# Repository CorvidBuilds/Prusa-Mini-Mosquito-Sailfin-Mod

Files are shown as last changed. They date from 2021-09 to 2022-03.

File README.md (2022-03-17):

# Prusa Mini Mosquito Sailfin Mod
Direct Drive Extruder Mounting Option for Prusa Mini
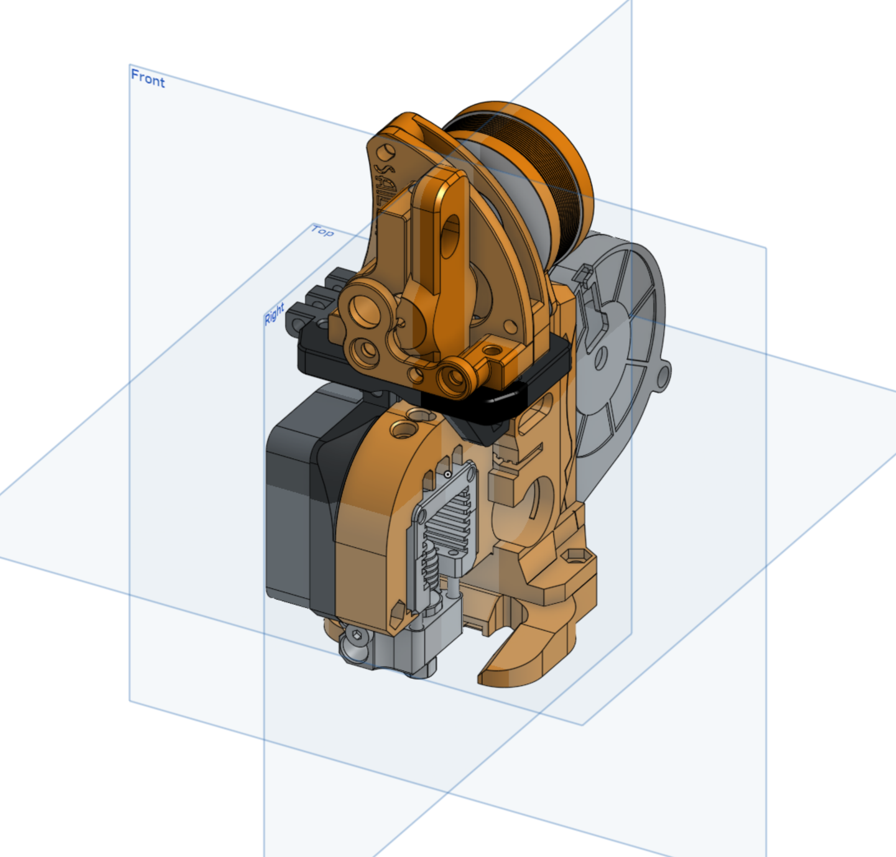
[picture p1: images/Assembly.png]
Assembly

I've been using 4nthonylin's [Mosquito Mount](https://www.prusaprinters.org/prints/36643-prusa-mini-mosquito-mount) and [Fan Shroud](https://www.prusaprinters.org/prints/37368-prusa-mini-mosquito-fan-shroud) mods for a long time and I've wanted to experiment with direct drive extruders for almost as long. I considered putting [Annex Engineering's Sherpa Mini](https://www.prusaprinters.org/prints/32331-prusa-mini-z-axis-bottom-redesign) using [athlon789789's mount](https://www.prusaprinters.org/prints/66519-prusa-mini-sherpa-extruder-direct-drive-conversion) but [CroXY's Sailfin](https://github.com/CroXY3D/Sailfin-Extruder) looked funnier. After some tinkering, I have created these two mounts.

I've been using this without issue since January 2022.

# List of modifications
The Mosquito mount was modified by:

- Removing two nut retainers.
- Removed M6 threading.
- Moved relief to the other side of the feeder hole.

The Sherpa Mini mount was modified by

- Aligning output of extruder with hot end.
- Widening the top plate for said alignment.
- Shortening the overall height by ~3mm.
- Adding a cutout to clear the Z Carriage.

This mount should fit both the Sherpa Mini and the Sailfin (using the Mid_Sherpa_Mount.stl).

# Instructions
- PTFE Length: 40.5mm 
# Klipper Config
Always confirm configurations will work for your system. The below is an example from what works on my Prusa Mini with the Buddy controller board and an LDO 36STH20-1004AHG.
```
#### Sailfin
[extruder]
step_pin: PD9
dir_pin: !PD8
enable_pin: !PD10
microsteps: 32
rotation_distance: 23.5976 
gear_ratio: 50:10
full_steps_per_rotation: 200	#200 for 1.8 degree, 400 for 0.9 degree
nozzle_diameter: 0.400
filament_diameter: 1.750
## Confirm your own thermistor config
# heater_pin: PB1
# sensor_type: ATC Semitec 104GT-2
# sensor_pin: PC0
max_extrude_only_velocity: 70
max_extrude_only_accel: 1500
min_temp: 10
max_temp: 305
## Confirm your own PA values
# pressure_advance = 0.028
# pressure_advance_smooth_time: 0.030
```

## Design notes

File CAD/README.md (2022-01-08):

# CAD Files
Found here: [OnShape](https://cad.onshape.com/documents/62063f3fcb23067bcaa5ab9b/w/d0a171f69a9cdb48ab1417f7/e/0df8f7e7769d611c5ae77dc3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)
Note: Ignore the mounting holes. Sailfin only provides the proprietary mounting holes in CAD instead of the ones that fit Sherpa *and* Sailfin.

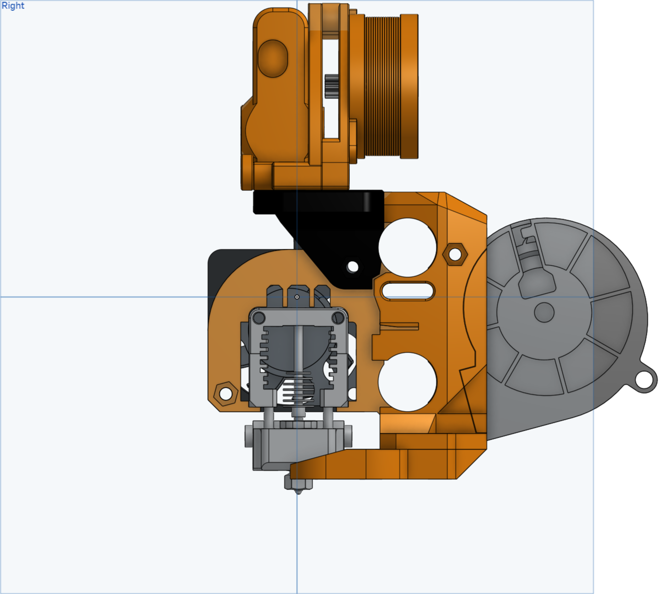
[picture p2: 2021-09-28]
images/Right.png

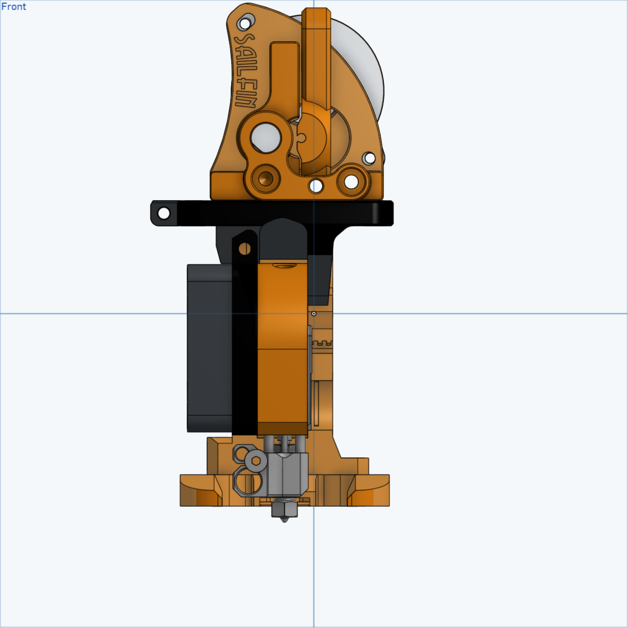
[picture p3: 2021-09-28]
images/Front.png

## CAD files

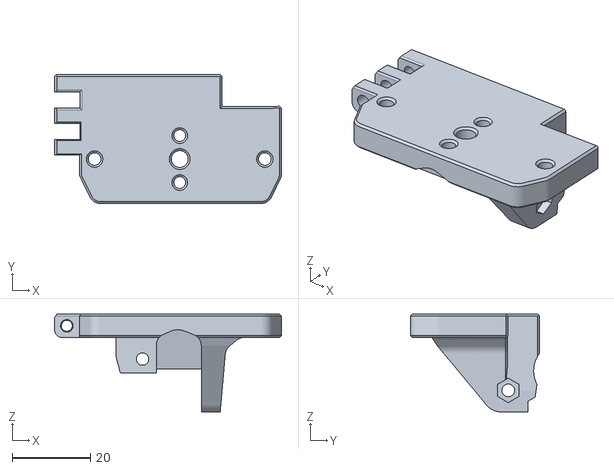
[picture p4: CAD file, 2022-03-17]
STLs/Sailfin Mount.stl
58.0 x 33.0 x 25.0

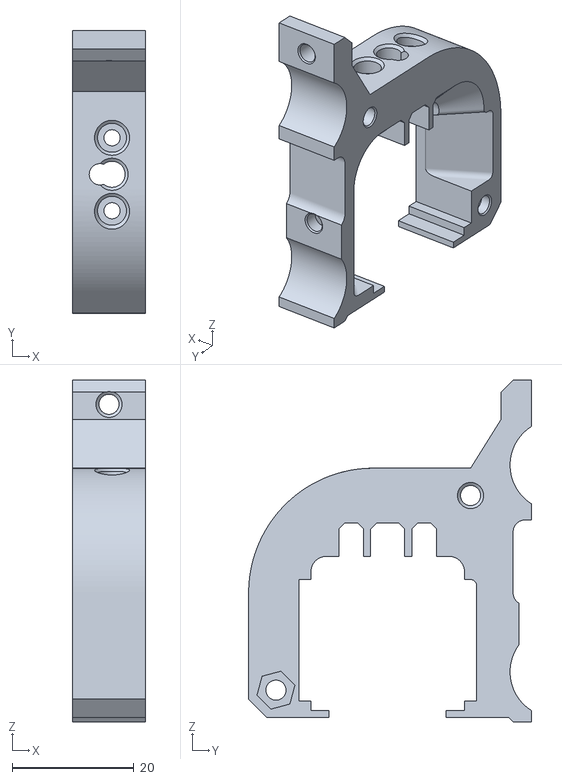
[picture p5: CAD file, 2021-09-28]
STLs/Mosquito Mount.stl
12.0 x 46.5 x 56.2

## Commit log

2021-09-28 Fix: Shorter Mount Conflicts with Z Carriage
    [Sailfin Mount.stl]
2021-09-28 Improve: rotated nut retainer to remove overhang
    [Sailfin Mount.stl]
2022-01-08 Create README.md
    Added CAD Link
2022-03-17 Improved clearances, updated readme
    [Sailfin Mount.stl]
